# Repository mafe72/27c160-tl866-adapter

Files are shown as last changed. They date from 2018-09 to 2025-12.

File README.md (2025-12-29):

# 27C322/160/800/400 EPROM Programming Adapter Series



## Introduction

This adapter converts the pin-outs of the parts listed below (which are similar to contemporary DIP-packaged mask ROMs) to 27C4096 pin-out as supported by the readily-available and cheap TL866 series of USB programmers.

The supported EPROMs parts are:
- **27C400:** 40-pin, 4Mbit (256k x 16-bit, 512k x 8-bit)
- **27C800:** 42-pin, 8Mbit (512k x 16-bit, 1M x 8-bit)
- **27C160:** 42-pin, 16Mbit (1M x 16-bit, 2M x 8-bit)
- **27C322:** 42-pin, 32Mbit (2M x 16-bit, no 8-bit access mode)

## Design

This adapter was designed using KiCad 5.0, you can find the project files on the folder called kicad-project.

Top Side:

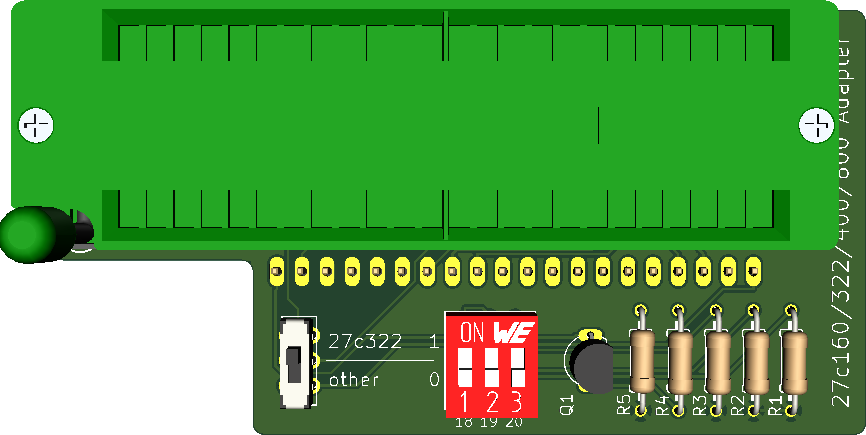
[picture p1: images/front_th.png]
top


Bottom Side:

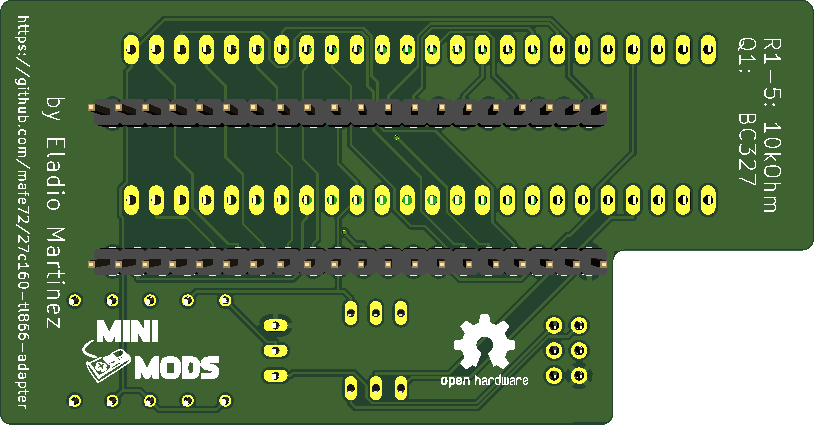
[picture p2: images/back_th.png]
bottom


## Usage

Insert the programming adapter into the TL866 with the socket handles adjacent to each other. Insert the EPROM into the lowest-possible position in the adapter and with pin 1 nearest the handle.

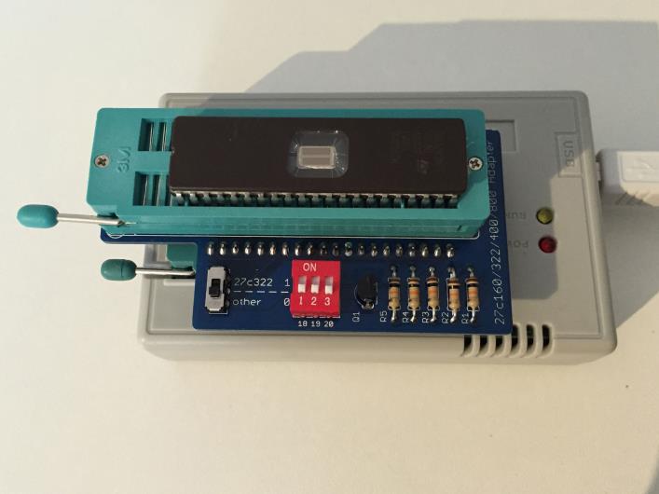
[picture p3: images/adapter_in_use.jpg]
Adapter when in use


If your are programming a 27C322 EPROMs, move the switch to the **Position 27c322**, for 27C160 , 27C400 and 27C800 EPROMs, switch must be in the **Position other**.

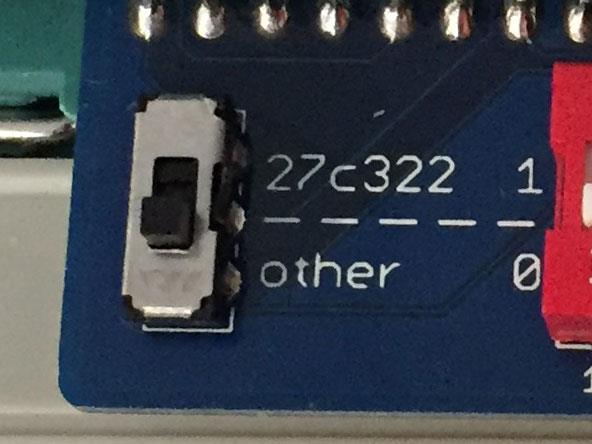
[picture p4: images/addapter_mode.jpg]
Adapter mode


## Software

The following instructions describe how to write a 27c160 EPROM.

Split the source EPROM into 512Kbytes parts, in this case I use the HJSplit, however other programs can be used.

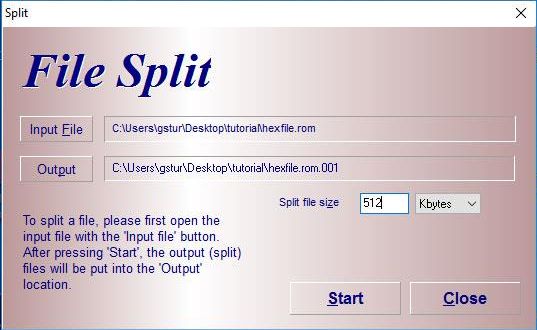
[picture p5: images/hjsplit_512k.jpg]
HJSplit


Located the output path, for this example four files of 512Kbyte size with the extension ending on ".001" - ".004".

Launch the MiniPro software, select `AMD 27C4096 DIP40` device, deselect `Check ID` and set `Pulse Delay` to `50us`. You may also optionally reduce `VPP Voltage` to `12.50V`, depending on your EPROM's datasheet and programming success.

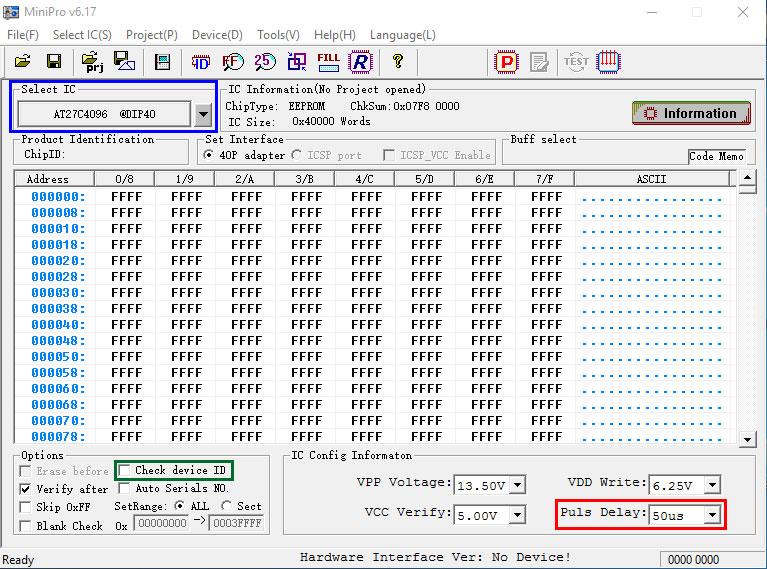
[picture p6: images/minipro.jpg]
MiniPro Software Configuration


The EPROM can now be accessed as if it were a 27C4096 device, 512kB at a time, as configured by the DIP Switch:

- **27C400:** program all 512kB in one pass.
- **27C800:** program in 2 (two) 512kB passes.
- **27C160:** program in 4 (four) 512kB passes.
- **27C322:** program in 8 (eight) 512kB passes.

Refer to the following table for DIP Switch configuration:

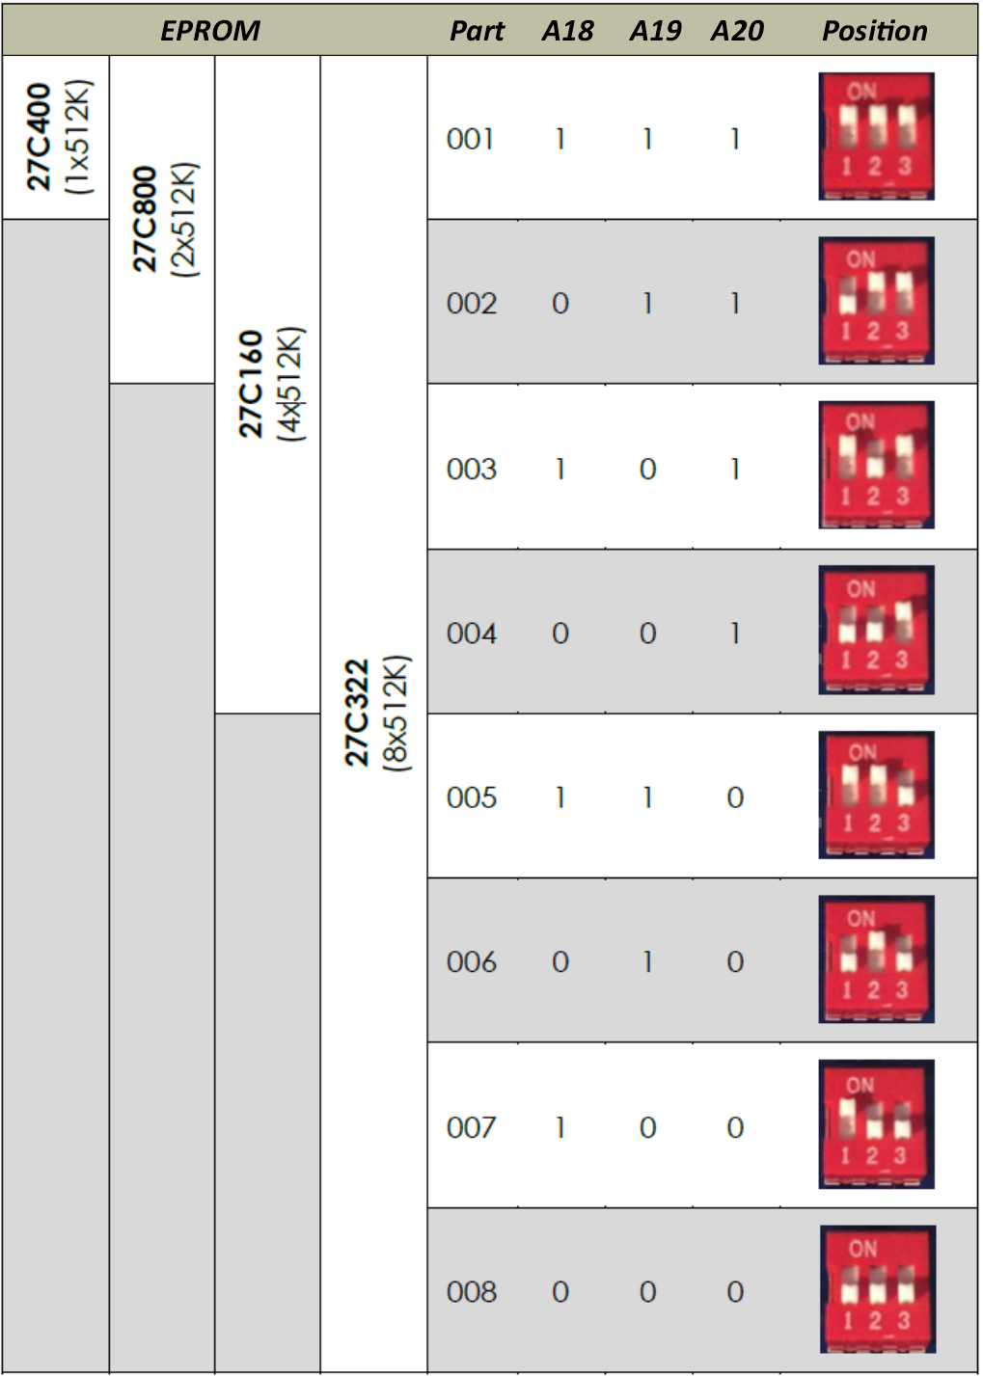
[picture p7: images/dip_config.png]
DIP Switch configuration


## Troubleshooting

If you suffer write or verify errors when programming, try these steps:

1. Make sure the EPROM is fully blank before programming it (`Device -> Blank Check`). All EPROMs available today are second-hand 'pulls'; sellers aren't always careful when erasing before resale.

2. Open and close the adapter's ZIF lever a few times, and reposition the EPROM squarely in the socket.

3. Try adjusting `VPP Voltage` between `12.50V` and `13.50V`. Subjectively, I have had greater success at the higher voltage, which gives headroom for voltage losses in transferring VPP through the adapter's logic.

4. Programming errors will occur occasionally, and of course, the chances increase the larger the device. It makes sense to invest in a UV eraser. These are available at a low cost on eBay for around $15-20. Most devices will be erased after 10 to 20 minutes under UV light.

5. [Maillouski](https://github.com/Maillouski/), reported that Xgpro v12.38 sets the default VDD Write value to 6.60V for the AT27C4096. To avoid programming issues, make sure you change this value to 3.30V.

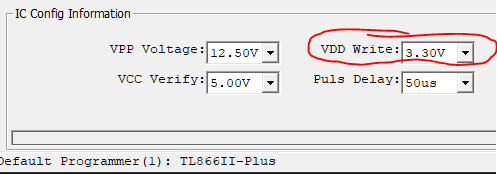
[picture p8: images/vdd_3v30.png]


6. [Tim aka BeepFixer](https://x.com/@beepfixer), shares his programming values for the **27C160** variants sourced from AliExpress.

   The main difference: the UV window pad configuration. call them Types A, B, and C.
    - **Type A**: 2x2 pads using only the center of the available window space 
    - **Type B**: 2x2 pads using most of the available window space 
    - **Type C**: 2x4 pads

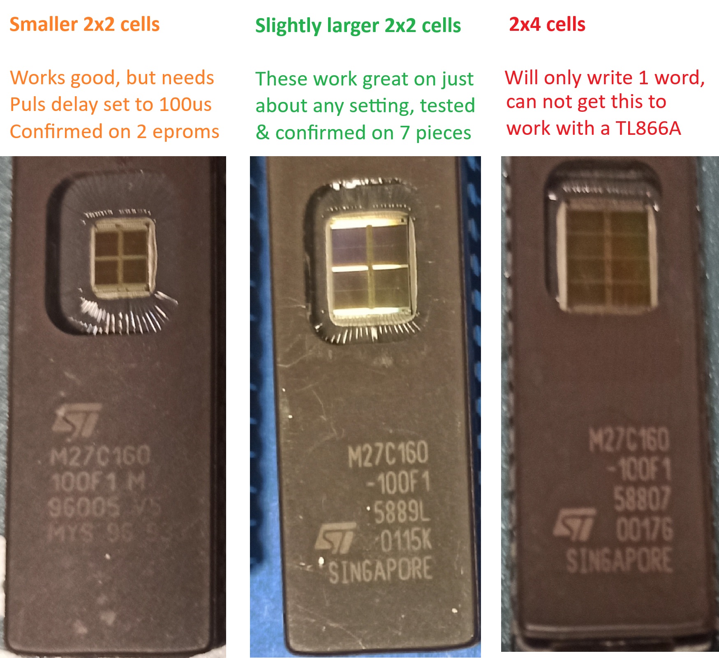
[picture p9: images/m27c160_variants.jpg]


**Testing Results**

  **Type A**: 2/10 chips needed a little TLC-a tiny tweak outside recommended settings (changing 50us 100us) made them programmable and verifiable. Just to be sure, here's the full settings used: VPP Voltage: 13.50V / VCC Verify:. 5.00V / VDD Write: 5.00V / Puls Delay: 100us. Although did have success with other voltages too, as long as the Puls Delay was at 100 and not 50us.

  **Type B**: 7/10 chips worked flawlessly- first try, recommended settings from Eladio (50us)

  **Type C**: 1/10 chip failed spectacularly. It reads and erases just fine, and can write a single word. But after the single word right it refuses to write more than that. Likely an older, stricter variant; not broken, just a silicon diva. I tried over and over again with different settings and can simply not get it to write a full batch. 

**Practical tips**

   - Always verify after programming. 
   - Try voltage differences as also mentioned in the adapter's GitHub.
   - And keep of file writes; since you will be using the adapter to write an image split into 4 sections, it is easy to write the wrong file to the wrong bank (oopsie, yes guilty of writing file 3 to bank 3 and 4 myself once). So, do verify the EPROM on the destination device!

## Hardware change log

R_20231123

* Fix EDG-03 DIP Switch's correct polarity.
* Update revision number to R_20231123
* Update Version number to 1.1

V_20180919

* Initial release.

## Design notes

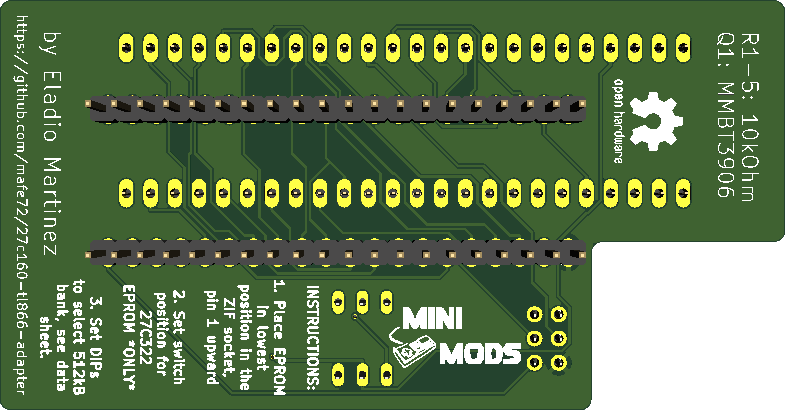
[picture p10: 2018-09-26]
images/back_smd.png

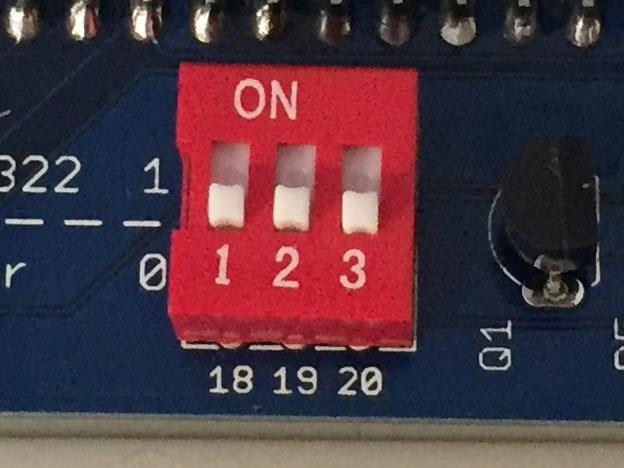
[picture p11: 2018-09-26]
images/adapter_dip.jpg

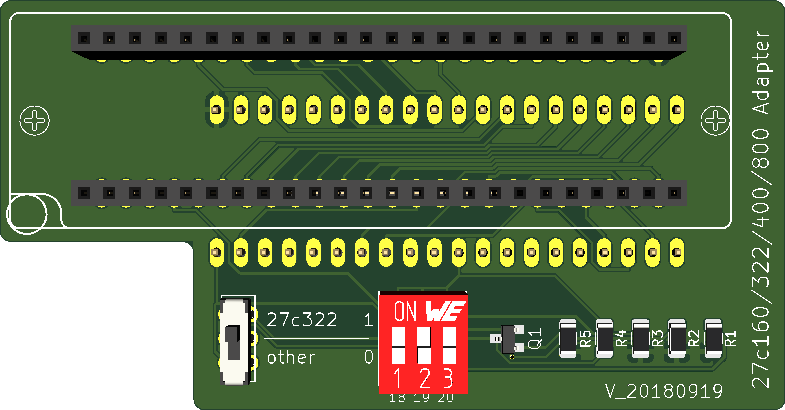
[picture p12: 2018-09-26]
images/front_smd.png

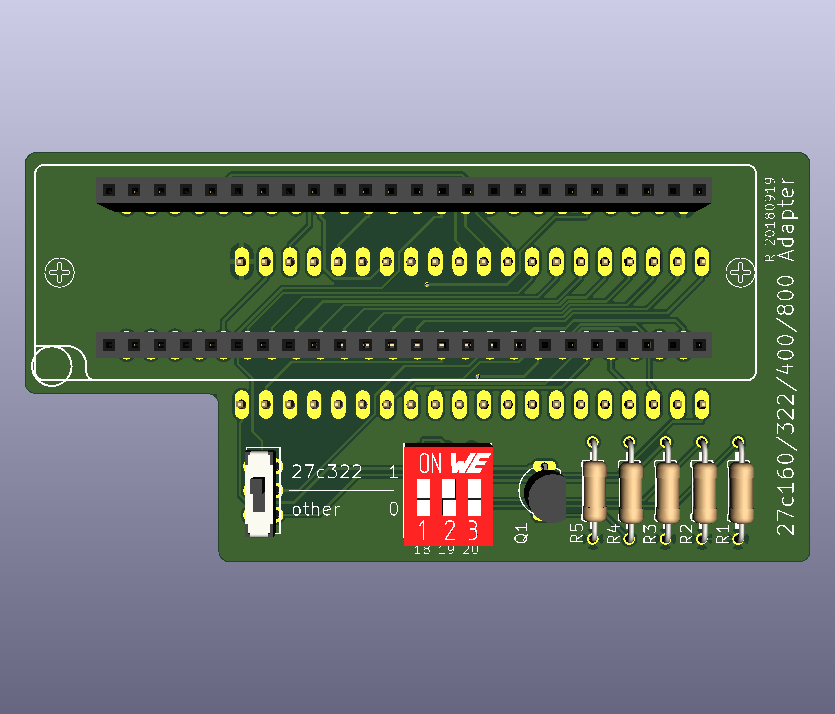
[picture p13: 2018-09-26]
kicad-project/front.png

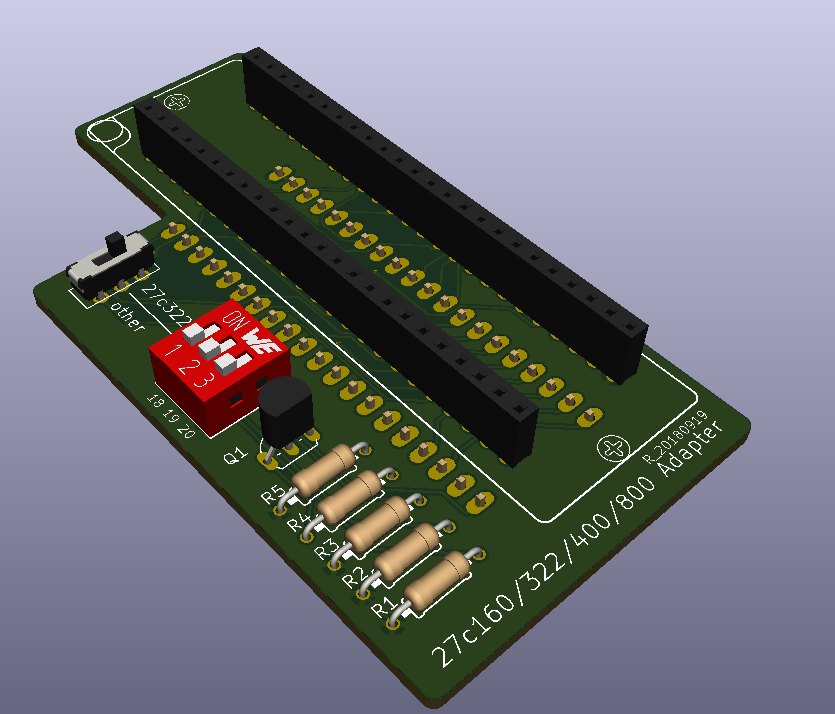
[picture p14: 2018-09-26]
kicad-project/iso.png

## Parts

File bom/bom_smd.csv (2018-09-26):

Component | Part | References | Value | MPN | Quantity Per PCB | Datasheet
1 | BC327 | Q1 | MMBT3906 | MMBT3906-7-F | 1 | https://media.digikey.com/pdf/Data%20Sheets/Diodes%20PDFs/MMBT3906.pdf
2 | R-EU_0207_10 | R1 R2 R3 R4 R5 | 10k | RC1206JR-0710KP | 5 | http://www.yageo.com/NewPortal/yageodocoutput?fileName=/pdf/R-Chip/PYu-RC_51_RoHS_P_0.pdf
3 | SW_DIP-3 | SW2 | DIP | BD03 | 1 | https://www.ckswitches.com/media/1331/bd.pdf
4 | MS22D16 | SW1 | MS22D16 | JS202011CQN | 1 | https://www.ckswitches.com/media/1422/js.pdf
5 | 27C4002 | U1 | 27C4002 | 61302011121 | 2 | https://katalog.we-online.de/em/datasheet/6130xx11121.pdf
6 | 3M_248-3345 | ZX1 | 3M_248-3345 | 248-1282-00-0602J | 1 | http://multimedia.3m.com/mws/media/494546O/3mtm-dip-sockets-100-2-54-mm-ts0365.pdf

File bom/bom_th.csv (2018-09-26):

Component | Part | References | Value | MPN | Quantity Per PCB | Datasheet
1 | BC327 | Q1 | BC327 | BC327 | 1 | https://media.digikey.com/pdf/Data%20Sheets/ON%20Semiconductor%20PDFs/BC327%20Rev3.pdf
2 | R-EU_0207_10 | R1 R2 R3 R4 R5 | 10k | CFR-25JB-52-10K | 5 | http://www.yageo.com/NewPortal/yageodocoutput?fileName=/pdf/throughhole/Yageo_LR_CFR_2013.pdf
3 | SW_DIP-3 | SW2 | DIP | BD03 | 1 | https://www.ckswitches.com/media/1331/bd.pdf
4 | MS22D16 | SW1 | MS22D16 | JS202011CQN | 1 | https://www.ckswitches.com/media/1422/js.pdf
5 | 27C4002 | U1 | 27C4002 | 61302011121 | 2 | https://katalog.we-online.de/em/datasheet/6130xx11121.pdf
6 | 3M_248-3345 | ZX1 | 3M_248-3345 | 248-1282-00-0602J | 1 | http://multimedia.3m.com/mws/media/494546O/3mtm-dip-sockets-100-2-54-mm-ts0365.pdf

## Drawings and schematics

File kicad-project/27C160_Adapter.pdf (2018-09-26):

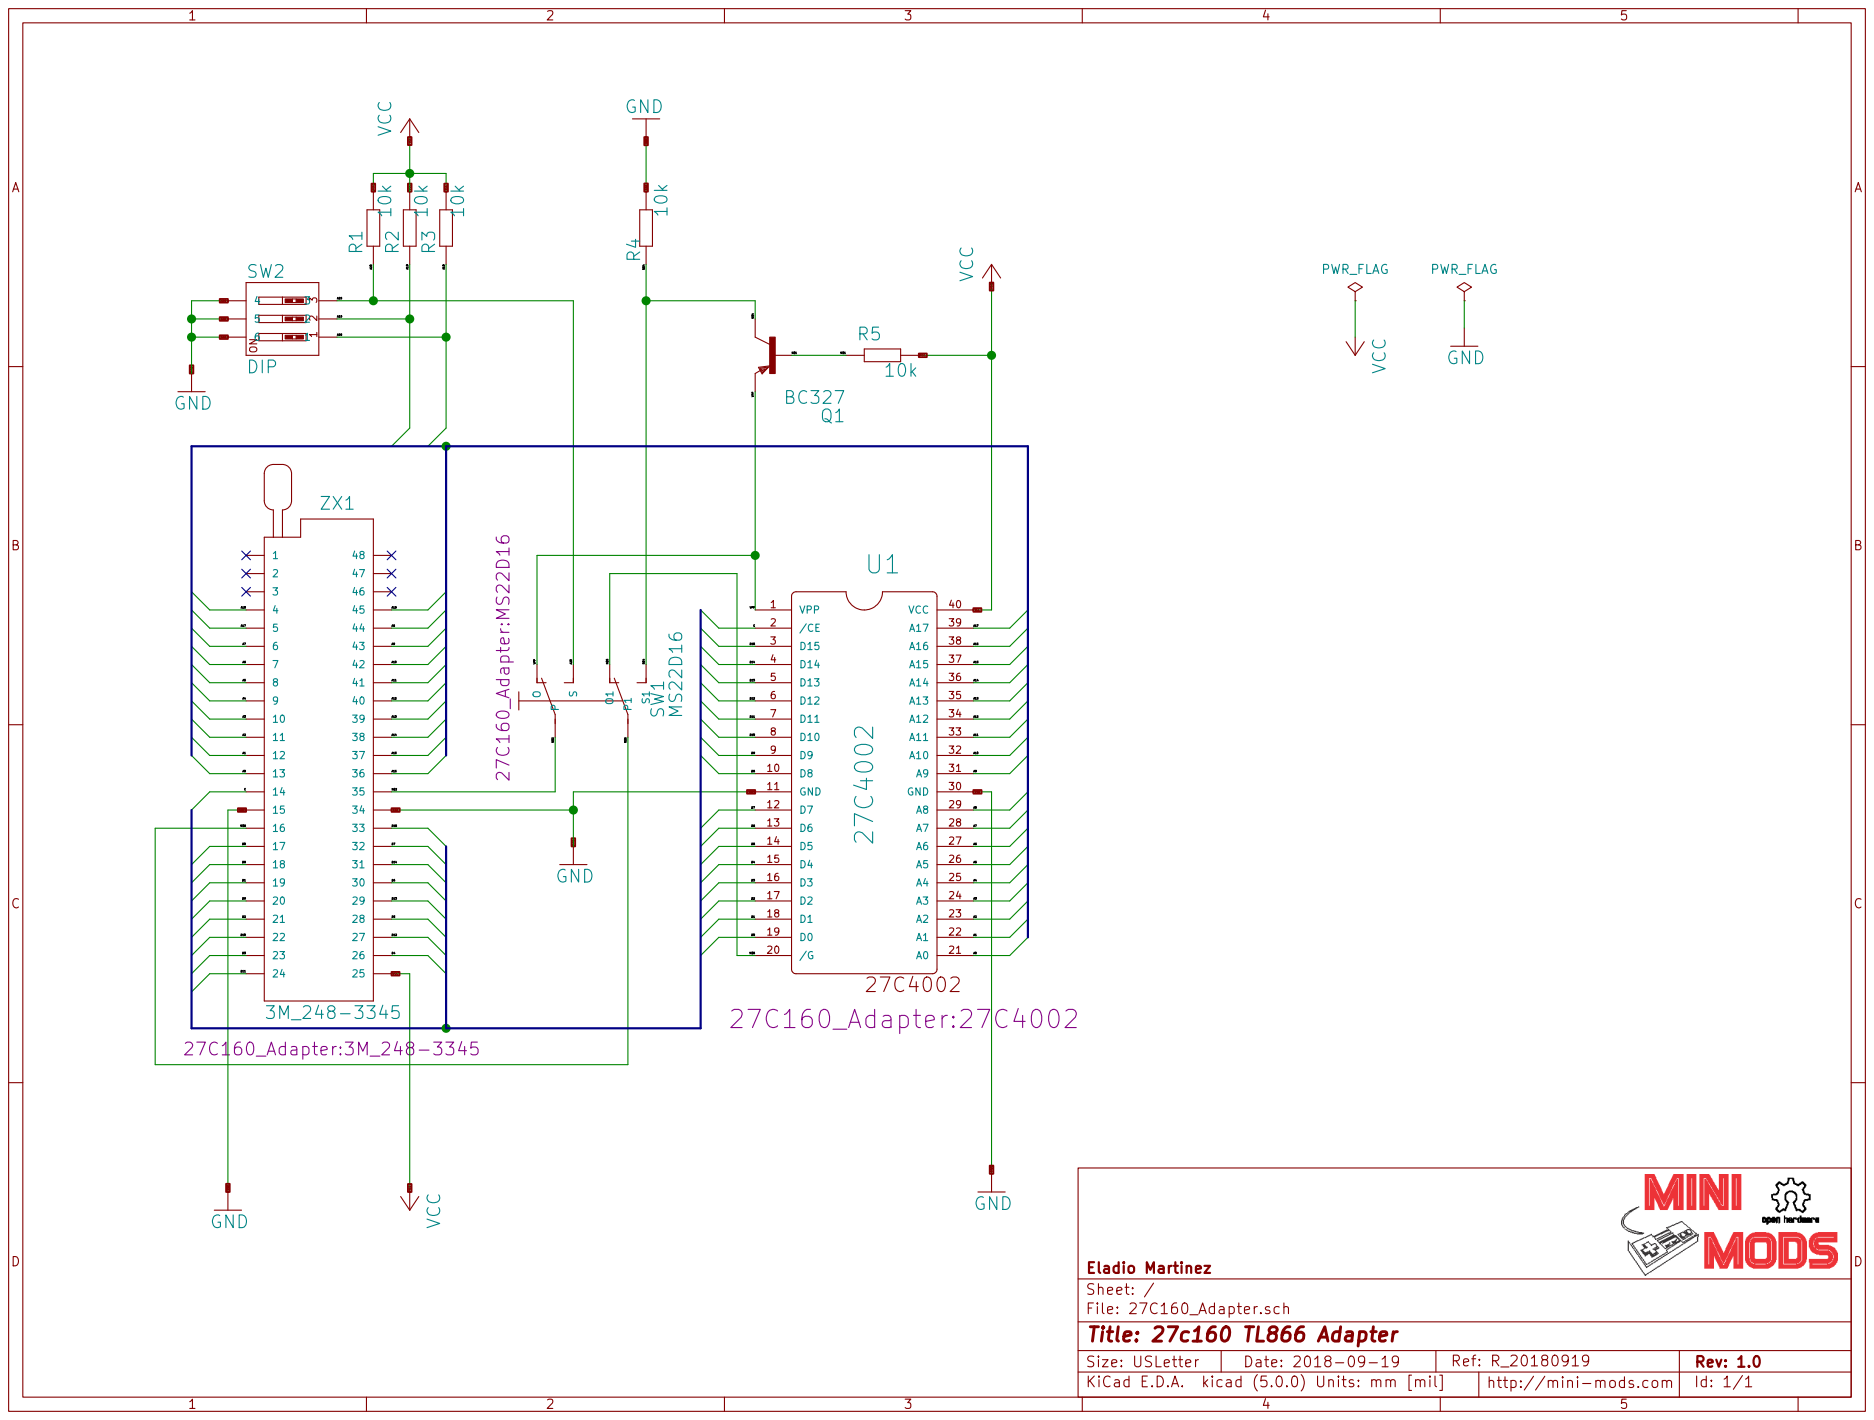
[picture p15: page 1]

File: 27C160_Adapter.sch Sheet: / Eladio Martinez | http://mini-mods.com Rev: 1.0 | D Date: 2018-09-19 KiCad E.D.A. kicad (5.0.0) Units: mm [mil] Size: USLetter

Ref: R_20180919

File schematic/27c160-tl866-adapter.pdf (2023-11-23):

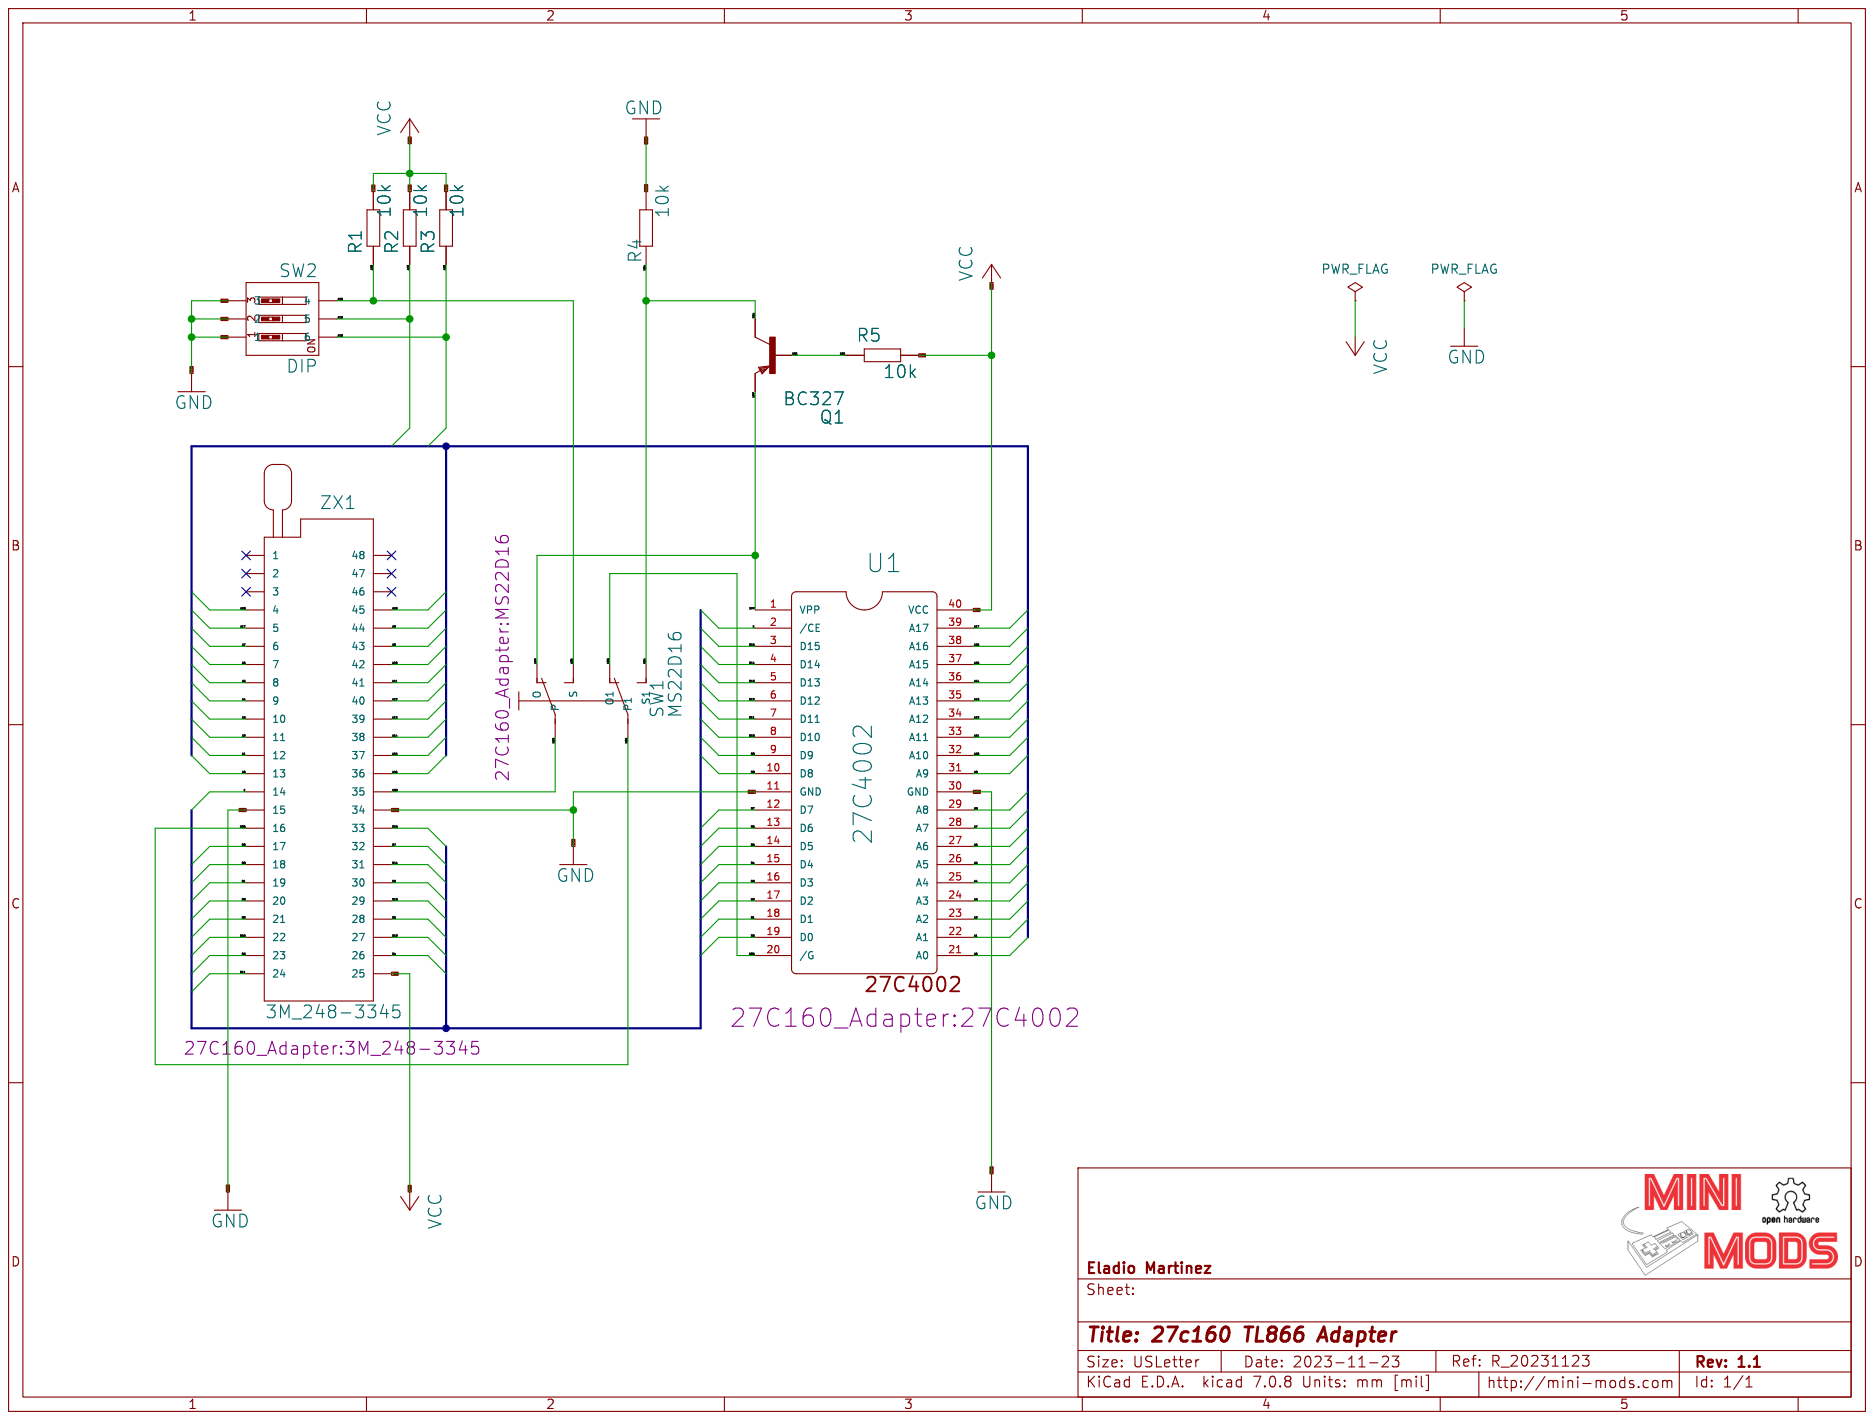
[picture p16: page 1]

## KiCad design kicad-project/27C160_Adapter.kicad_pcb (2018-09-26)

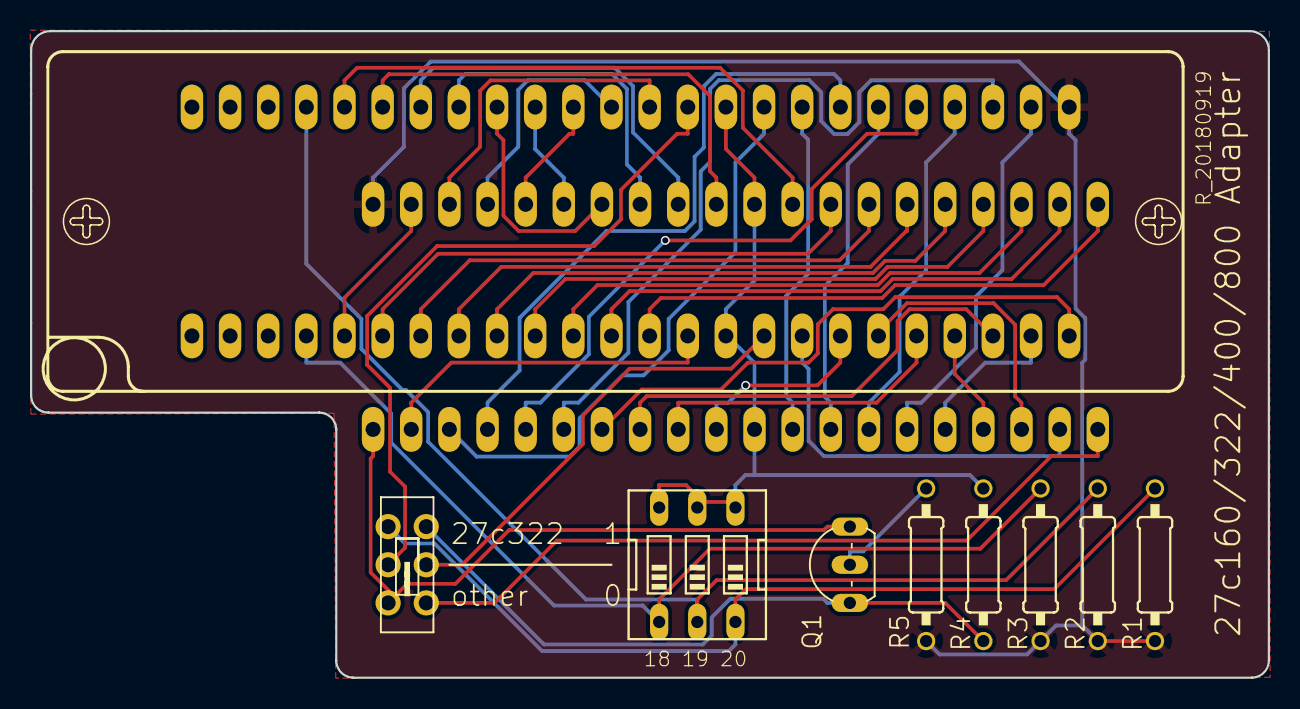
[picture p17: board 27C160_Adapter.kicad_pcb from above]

Board: 2 copper layers, 82.4 x 43.1 mm, 12 parts (0 on the bottom side), 46 nets.

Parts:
G001: LOGO; mini-mods
Q1: BC327; TO92-EBC
R1, R2, R3, R4, R5: 10k; 0207%2f10
REF01: OSHW-Logo2_9.8x8mm_SilkScreen
SW1: MS22D16
SW2: DIP; EDG-03
U1: 27C4002
ZX1: 3M_248-3345

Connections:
/A0: U1.21, ZX1.13
/A1: U1.22, ZX1.12
/A2: U1.23, ZX1.11
/A3: U1.24, ZX1.10
/A4: U1.25, ZX1.9
/A5: U1.26, ZX1.8
/A6: U1.27, ZX1.7
/A7: U1.28, ZX1.6
/A8: U1.29, ZX1.44
/A9: U1.31, ZX1.43
/A10: U1.32, ZX1.42
/A11: U1.33, ZX1.41
/A12: U1.34, ZX1.40
/A13: U1.35, ZX1.39
/A14: U1.36, ZX1.38
/A15: U1.37, ZX1.37
/A16: U1.38, ZX1.36
/A17: U1.39, ZX1.5
/A18: R3.1, SW2.1, ZX1.4
/A19: R2.1, SW2.2, ZX1.45
/A20: R1.1, SW1.3, SW2.3
/D0: U1.19, ZX1.17
/D1: U1.18, ZX1.19
/D2: U1.17, ZX1.21
/D3: U1.16, ZX1.23
/D4: U1.15, ZX1.26
/D5: U1.14, ZX1.28
/D6: U1.13, ZX1.30
/D7: U1.12, ZX1.32
/D8: U1.10, ZX1.18
/D9: U1.9, ZX1.20
/D10: U1.8, ZX1.22
/D11: U1.7, ZX1.24
/D12: U1.6, ZX1.27
/D13: U1.5, ZX1.29
/D14: U1.4, ZX1.31
/D15: U1.3, ZX1.33
/E: U1.2, ZX1.14
/N$1: Q1.B, R5.2
/N$2: SW1.2, ZX1.35
/N$4: Q1.C, R4.2, SW1.6
/N$5: SW1.4, U1.20
/N$6: SW1.5, ZX1.16
/VPP: Q1.E, SW1.1, U1.1
GND: R4.1, SW2.4, SW2.5, SW2.6, U1.11, U1.30, ZX1.15, ZX1.34
VCC: R1.2, R2.2, R3.2, R5.1, U1.40, ZX1.25

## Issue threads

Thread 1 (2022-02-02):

Dipswitch is the wrong way around

MarkieV, 2022-02-02:
Hi there

Thank you for this adapter I use it a lot, but on your PCB layout your dipswitch is the wrong way around.

You use pullups to make address lines A18/A19/A20 high, and use the dipswitch to connect the address
lines to ground, so when you set a dipswitch to ON (also 1 on your PCB design) this address line is
actually connected to ground and will never be a 1 :-)

Simple fix is to mount the dipswitch 180 degrees, but for people with OCD this is hard to swallow :-)

Grtzz  Mark

bmthr, 2022-02-03:
Hi Mark,

Thank you for your notice!

PCB isn't my design , but I'll check this and try to repair pcb ways in other revision of this adapter.

Thank You!

BR

Marijan

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

zitev, 2022-05-15:
@MarkieV @bmthr
Hi,
I now have some pain in the ass with tl866II plus and M27C160 adapter. The DIP switch on my copy is also in the position shown in the published drawing, so according to the explanation for M27C160, all three DIPs are in the On position (to
bank 0 ), but this way these legs are on the ground, the writing stops with an error (it stops in the opposite position in the same way, I don't know where the error is yet.) What is the tendency at the moment? Is the implantation position of my DIP good or not?

Thanks for help,
zitev

Pachecon88, 2022-12-30:
El esquemático está actualizado ???? O presenta ese herror todavía???

Pachecon88, 2023-05-02:
Bueno nadie me a dado respuesta pero creo que usando esa combinación funciona ok... Estoy esperando las m27c160 a ver que sucede.... El único problema que e visto es que en la tabla de posiciones del inteructor donde dice que es 1 es un 0 o viceversa... Saludos 👍

mafe72, 2023-11-23:
I have fixed the EDG-03 DIP Switch's correct polarity for the SMD and TH gerber folder, also I have updated the schematic to reflect the correct dip switch orientation.

Pachecon88, 2023-11-23:
> He corregido la EDG-03 del Interruptor DIP de la polaridad correcta para el SMD y TH gerber carpeta, también he actualizado el esquema para reflejar la correcta interruptor dip de orientación.

Gracias mi amigo al final me funciono como estaba el problema era un problema de interpretación del esquema...Se me había olvidado comentar el resultado..👍👍👍

Closed 2023-11-23.

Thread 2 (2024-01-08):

T48

nbdy32, 2024-01-08:
HI, is it possible tu use this adapter with T48 programmer ??? (TL866-3G) ???

L10N37, 2024-01-29:
They sell adapters for that on ali express. I was here to ask about MX29F1615 used in adapter as I threw this together on a breadboard, just opened it in kicad and traced out every connection. It worked fine multiple times on personal pulls out of a Naomi 1 and Naomi 2, but I just tried a batch of 30 (3 lots of 10, from eBay and ali express, all different sellers) and they all blank check fine after UV erase (well most of them), but then fail instantly in flashing.

I want to use MX29F1615 instead.

Here is one for you:

https://www.aliexpress.com/item/1005004743064970.html

If dev see this, please let me know if this will work on the flash chip stated :)

mafe72, 2024-02-02:
> HI, is it possible tu use this adapter with T48 programmer ??? (TL866-3G) ???

nbdy32,
I just got my TL866-3G from aliexpress and I can confirm this adapter works with the T48.

mafe72, 2024-02-02:
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

L10N37,
This adapter will not work with the MX29F1615.

Chris Hooper have designed a programmer for this EEPROM, you can find his excellent writeup and instructions at http://eebugs.com/mx29f1615
The hardware and firmware for the programmer are available on his GitHub at https://github.com/cdhooper/mx29f1615_programmer/tree/main/

Good luck!

mafe72, 2024-02-02:
Thanks for your interest in this adapter!

L10N37, 2024-02-03:
Thanks! I have an STM discovery board in the cupboard but it's a recently released one. I'll check out its compatibility.

Maybe a T56 is on the line up which is drop in for everything mentioned here. Around $290 AUD at the moment shipped from China... steep.

Closed 2024-02-02.

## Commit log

2023-11-23 Fix EDG-03 DIP Switch's correct polarity
    R_20231123
    Fix EDG-03 DIP Switch's correct polarity.
    Uppdate revision number to R_20231123
    Update Version number to 1.1
2023-11-23 Create gerber
2023-11-23 Fix EDG-03 DIP Switch's correct polarity
    Update revision number to R_20231123
    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
    [27C160_Adapter-B_Cu.gbl, 27C160_Adapter-B_Mask.gbs, 27C160_Adapter-B_Paste.gtp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]
2025-01-15 IC config VDD Write 3.30V
